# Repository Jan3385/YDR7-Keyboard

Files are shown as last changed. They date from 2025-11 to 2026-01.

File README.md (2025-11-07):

# YDR7-Keyboard

A mechanical keyboard build on YD-RP2040 with an OLED display and backlights

Build for **MX** switches

A sligthly modified 96% keyboard layout with 4 extra keys for managing onboard firmware (103 keys total)

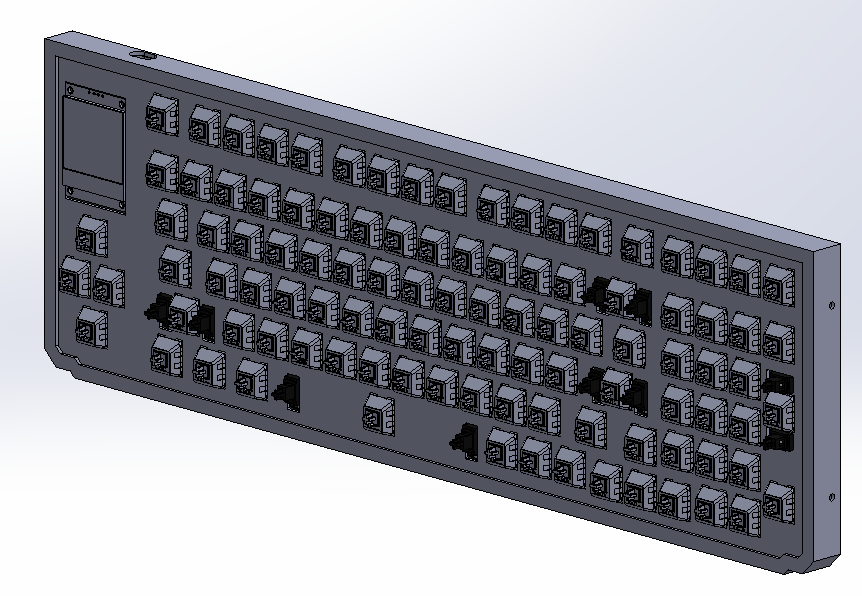
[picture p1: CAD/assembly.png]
Keyboard CAD assembly


Keyboard layout

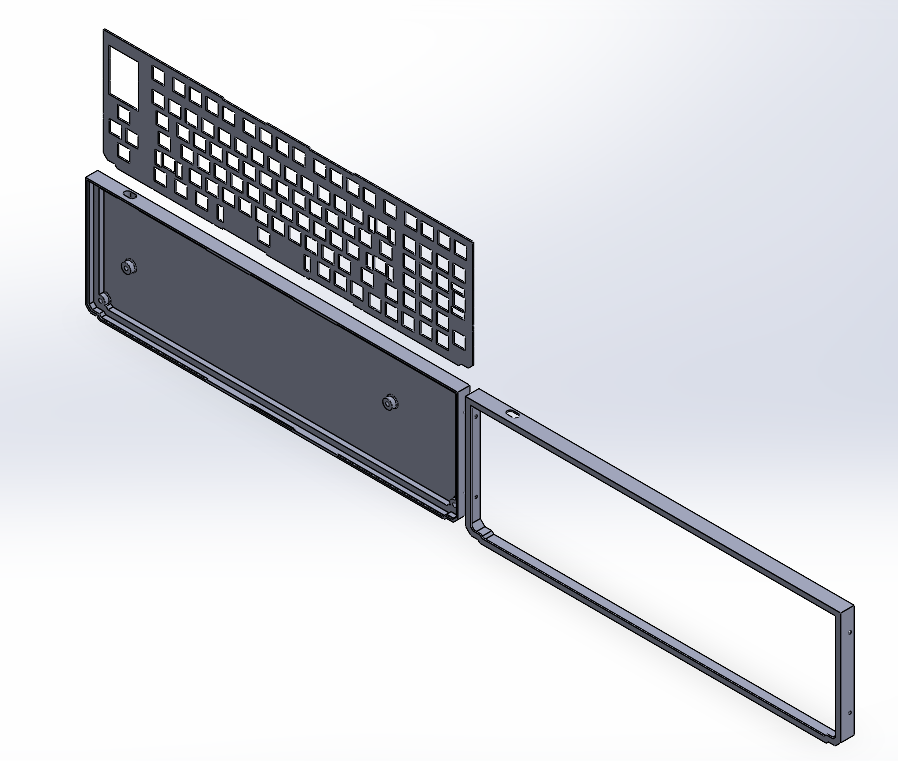
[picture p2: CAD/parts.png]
Keyboard parts


## Why is this one special

It's a keyboard with a customisable OLED that helps to manage, and control parts of the firmware like changing backlighting color, showing typing speed and much more

The firmware is also open-source so anyone can customise and add features to their keyboard

## PCB

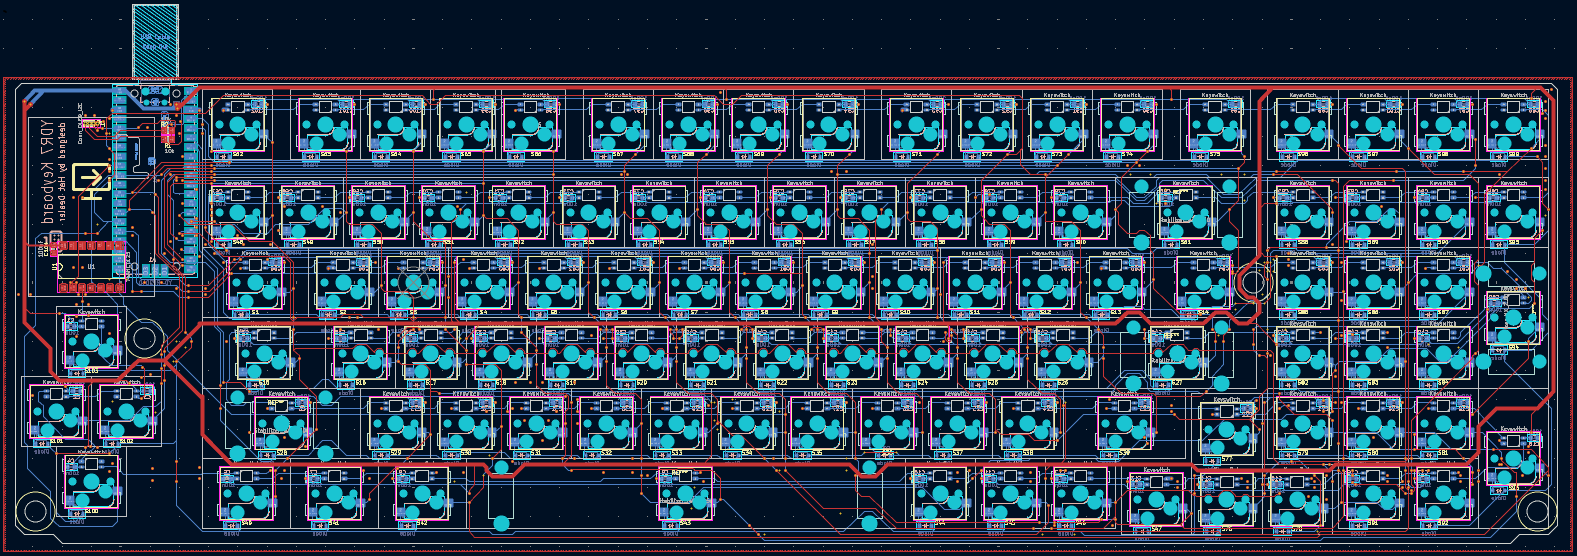
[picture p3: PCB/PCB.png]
PCB


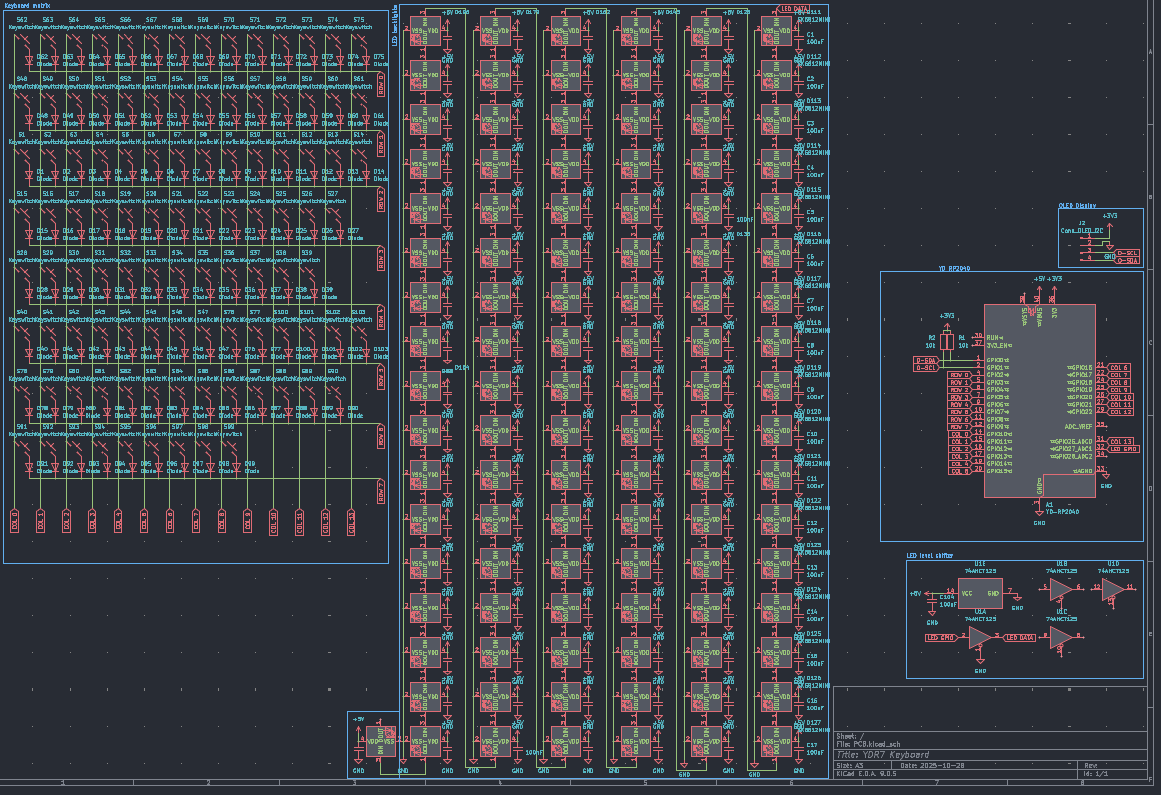
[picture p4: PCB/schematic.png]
Schematic


The keyboard uses a custom PCB with the YD-RP2040 attached to it providing a USB-C connection along with power to the board

The YD-RP2040 is the devboard with a chip running this project. You may be able to use a standard Raspberry PI pico but that was not tested

## Case

The keyboard is comprised out of 3 parts. The panel which holds the switches, a back panel and a front panel

Due to their size its impossible to print an entire piece at once, thats why there are sliced versions in the `CAD/Sliced` folder. You can print them separately and then weld them with a soldering iron together. You should weld the front and the back piece but not the panels as they are held together by the frame anyway

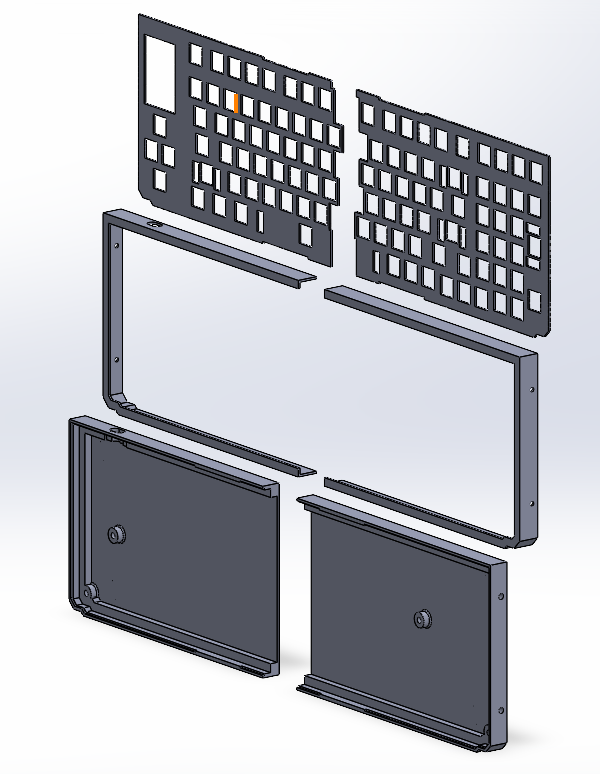
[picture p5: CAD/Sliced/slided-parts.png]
Sliced case


> [!WARNING]
> Due to the size of the keyboard, even the sliced version requires 216 x 139 mm or larger printing plate

## Compiling & flashing firmware

> [!NOTE]
> You should have CMAKE and GCC installed along with Arm embedded GNU Toolchain `arm-none-eabi-gcc`

For compilation run the following commands in the project folder:
Note that the first command may take a while as it is downloading the SDK from git

> cmake -S Firmware -B Firmware/build -G "Ninja"

> cmake --build Firmware/build --target Keyboard_Firmware

To load the firmware into the RP2040 chip, press the **BOOT** button on the YD-RP2040 devboard and plug it into your computer. It should appear as a drive in which you insert the `Keyboard_Firmware.uf2` file inside the `Firmware/build/` folder. The keyboard should reboot itself and load the active firmware

To reflash the board just repeat the steps above

## BOM

| Product name | Product description | Product link | Product unit cost inc. Tax (€) | Product amount | Product total cost (€) | Running total (€ with tax and shipping) |
|---|---|---|---|---|---|---|
| YD-RP2040 | RPI pico-like microcontroller board | [Link](https://www.aliexpress.com/item/1005006152339711.html) | 2.99 € | 1 | 2.99 € | 2.99 € |
| 74AHCT125DR | Logic level shifter IO | [Link](https://www.aliexpress.com/item/1005010022053816.html) | 3.01 € | 1 | 3.01 € | 6.00 € |
| 100nF 0805 Ceramic Capacitor (>= 6.3V) | Decoupling capacitor | [Link](https://www.aliexpress.com/item/1005007470747384.html) | 0.02 € | 105 | 1.82 € | 7.82 € |
| 10kΩ 0805 Resistor | Pull-up resistor | [Link](https://www.aliexpress.com/item/1005009805187579.html) | 0.02 € | 2 | 0.04 € | 7.85 € |
| 1N4148W Diode | Keyboard matrix diode | [Link](https://www.aliexpress.com/item/4000685043735.html) | 0.02 € | 103 | 1.77 € | 9.63 € |
| Kailh Hot-Swap Sockets for Gateron x103 | PCB sockets for switches | [Link](https://www.aliexpress.com/item/1005009594313632.html) | 8.24 € | 1 | 8.24 € | 17.87 € |
| Gateron Switch G Pro 3.0 | Mechanical keyboard switches | [Link](https://kurokeeb.com/products/gateron-switch-g-pro-3-0) | 0.37 € | 103 | 38.11 € | 55.98 € |
| 1.5 Inch OLED Display 128x128 I2C | OLED Screen | [Link](https://www.aliexpress.com/item/1005009409829497.html) | 4.25 € | 1 | 4.25 € | 60.23 € |
| SK6812 Mini RGB LED x200 | Backlight LEDs | [Link](https://www.aliexpress.com/item/1005007696173500.html) | 3.38 € | 2 | 6.76 € | 66.99 € |
| Keycap set | set of keycaps for keyboard | [Link](https://www.aliexpress.com/item/1005007996240625.html) | 16.93 € | 1 | 16.93 € | 83.92 € |
| M3x8 screws | screws for PCB and case assembly | [Link](https://www.aliexpress.com/item/1005008585550992.html) | 0.05 € | 8 | 0.40 € | 84.32 € |
| Hot melt inserts MxL4xOD4.2 | inserts for case assembly | [Link](https://www.aliexpress.com/item/1005006071488810.html) | 0.11 € | 8 | 0.88 € | 85.20 € |
| Silicone feet 12x3mm x4 | anti-slip feet for case | [Link](https://www.aliexpress.com/item/1005006954839245.html) | 0.72 € | 1 | 0.72 € | 85.92 € |
| PCB | w/o assembly (estimate) | [Link](https://www.jlcpcb.com/) | 40.00 € | 1 | 40.00 € | 125.92 € |

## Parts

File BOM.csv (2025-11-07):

Product name | Product description | Product link | Product unit cost inc. Tax (€) | Product amount | Product total cost (€) | Running total (€ with tax and shipping)
YD-RP2040 | RPI pico-like microcontroller board | https://www.aliexpress.com/item/1005006152339711.html | 2.99 € | 1 | 2.99 € | 2.99 €
74AHCT125DR | Logic level shifter IO | https://www.aliexpress.com/item/1005010022053816.html | 3.01 € | 1 | 3.01 € | 6.00 €
100nF 0805 Ceramic Capacitor (>= 6.3V) | Decoupling capacitor | https://www.aliexpress.com/item/1005007470747384.html | 0.02 € | 105 | 1.82 € | 7.82 €
10kΩ 0805 Resistor | Pull-up resistor | https://www.aliexpress.com/item/1005009805187579.html | 0.02 € | 2 | 0.04 € | 7.85 €
1N4148W Diode | Keyboard matrix diode | https://www.aliexpress.com/item/4000685043735.html | 0.02 € | 103 | 1.77 € | 9.63 €
Kailh Hot-Swap Sockets for Gateron x103 | PCB sockets for switches | https://www.aliexpress.com/item/1005009594313632.html | 8.24 € | 1 | 8.24 € | 17.87 €
Gateron Switch G Pro 3.0 | Mechanical keyboard switches | https://kurokeeb.com/products/gateron-switch-g-pro-3-0 | 0.37 € | 103 | 38.11 € | 55.98 €
1.5 Inch OLED Display 128x128 I2C | OLED Screen | https://www.aliexpress.com/item/1005009409829497.html | 4.25 € | 1 | 4.25 € | 60.23 €
SK6812 Mini RGB LED x200 | Backlight LEDs | https://www.aliexpress.com/item/1005007696173500.html | 3.38 € | 2 | 6.76 € | 66.99 €
Keycap set | set of keycaps for keyboard | https://www.aliexpress.com/item/1005007996240625.html | 16.93 € | 1 | 16.93 € | 83.92 €
M3x8 screws | screws for PCB and case assembly | https://www.aliexpress.com/item/1005008585550992.html | 0.05 € | 8 | 0.40 € | 84.32 €
Hot melt inserts MxL4xOD4.2 | inserts for case assembly | https://www.aliexpress.com/item/1005006071488810.html | 0.11 € | 8 | 0.88 € | 85.20 €
Silicone feet 12x3mm x4 | anti-slip feet for case | https://www.aliexpress.com/item/1005006954839245.html | 0.72 € | 1 | 0.72 € | 85.92 €
PCB | w/o assembly (estimate) | https://www.jlcpcb.com/ | 40.00 € | 1 | 40.00 € | 125.92 €

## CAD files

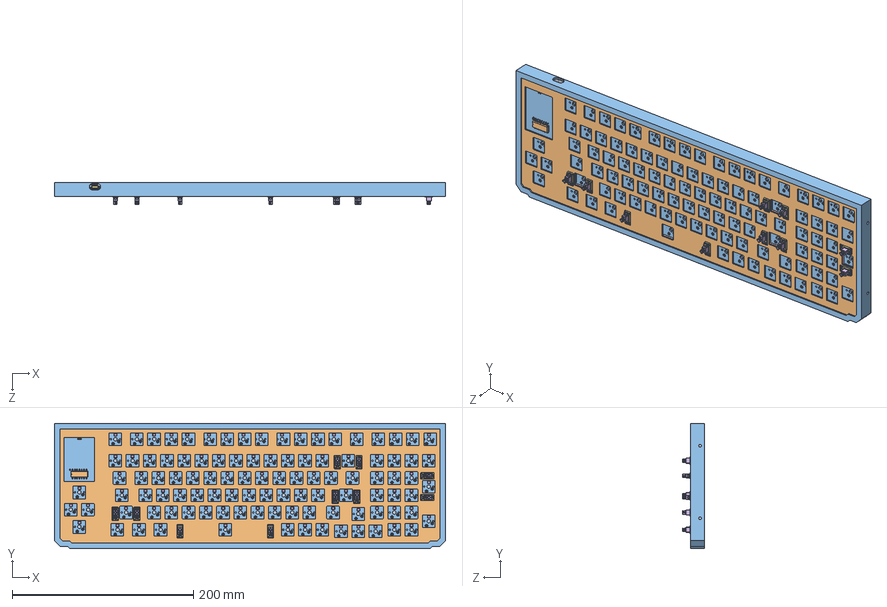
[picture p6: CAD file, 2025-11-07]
CAD/Assembly.STEP
431.7 x 138.0 x 24.4 mm
back
plate
front
Pins.step x 103
Body.step x 103
RaspberryPi_Pico_Module_KiCad.step
Hotswap_MX.step x 103
SMDIP-14_W11.48mm.step
C_0805_2012Metric.step x 105
R_0805_2012Metric.step x 2
Stabilizer_MX_2.00u.step x 4
PinHeader_1x04_P1.00mm_Vertical.step
Stabilizer_MX_6.25u.step
Diode_SOD-123.step x 103
PCB_PCB.step

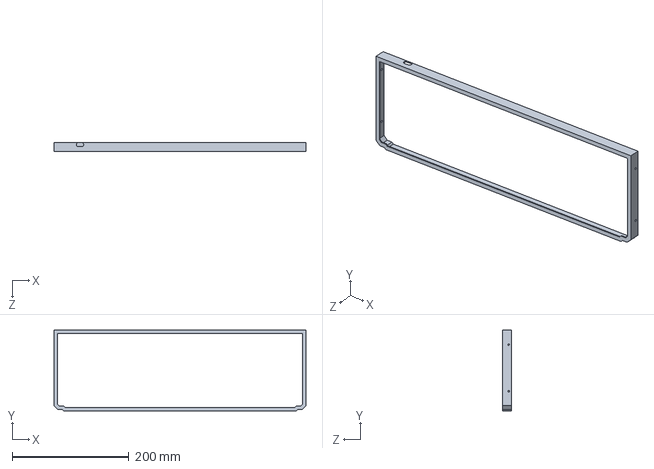
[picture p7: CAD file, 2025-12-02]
CAD/front.SLDPRT
431.7 x 138.0 x 15.6 mm

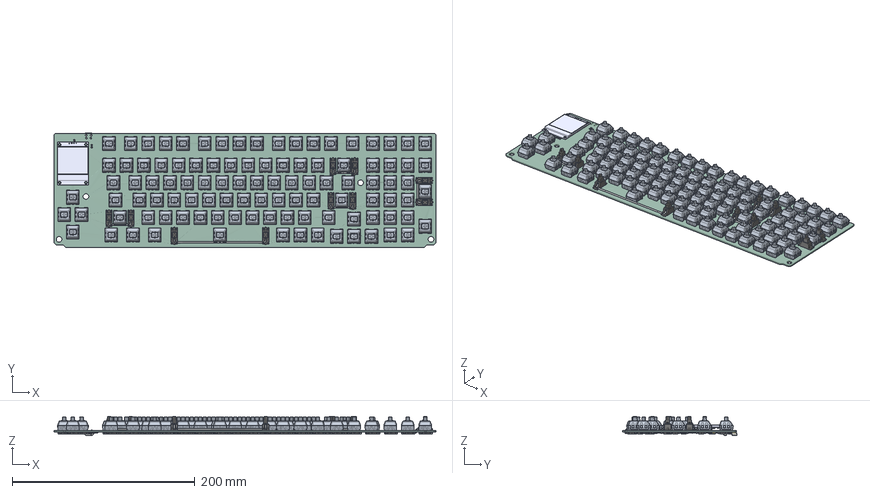
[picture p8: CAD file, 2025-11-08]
PCB/PCB.step
418.3 x 125.4 x 20.8 mm
Hotswap_MX x 103
PCB 1.2.1 x 103
SMDIP-14_W11.48mm
C_0805_2012Metric x 105
R_0805_2012Metric x 2
Stabilizer_MX_2.00u x 4
PinHeader_1x04_P1.00mm_Vertical
Part1_without header pins
Stabilizer_MX_6.25u
Pins x 103
Diode_SOD-123 x 103
RaspberryPi_Pico_Module_KiCad
PCB_PCB

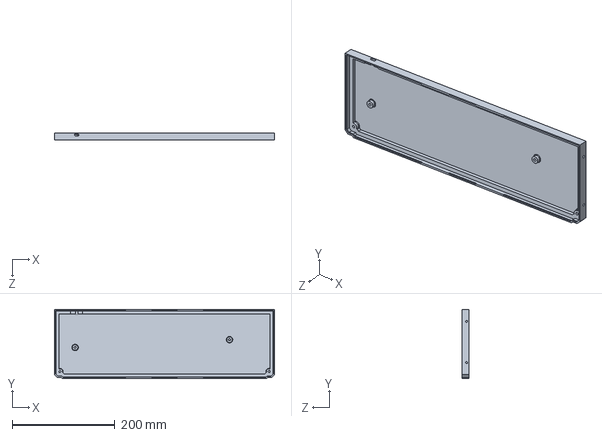
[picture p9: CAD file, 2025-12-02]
CAD/Back.SLDPRT
428.3 x 134.6 x 14.0 mm

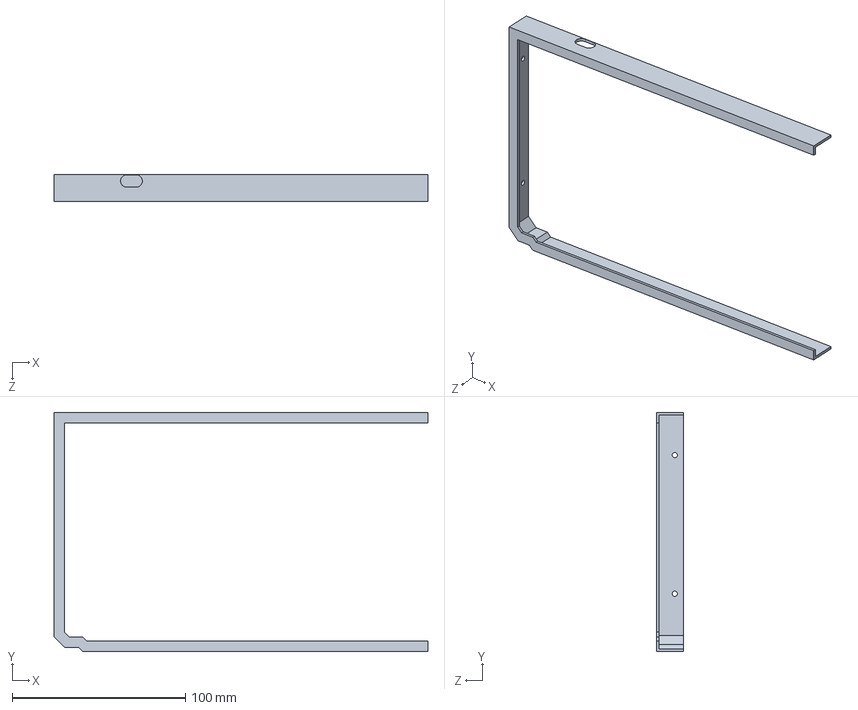
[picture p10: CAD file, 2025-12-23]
CAD/Sliced/1-front.STEP
215.8 x 138.0 x 15.6 mm

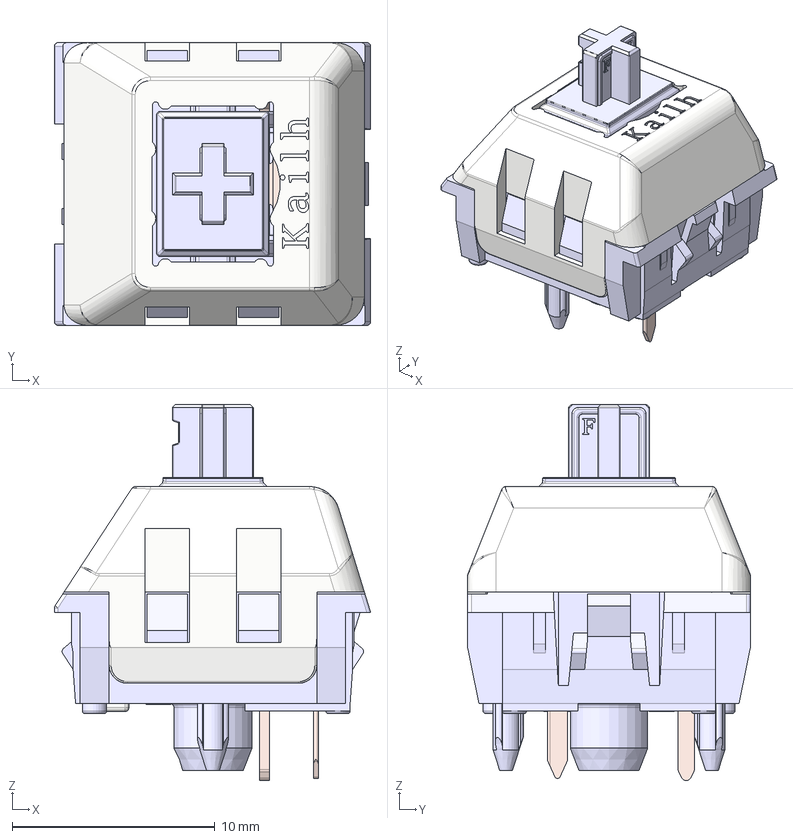
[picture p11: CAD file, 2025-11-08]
PCB/Kailh Polia.step
15.6 x 14.0 x 18.5 mm
Housing
ThickContact
SpringContact
Stem
Lid

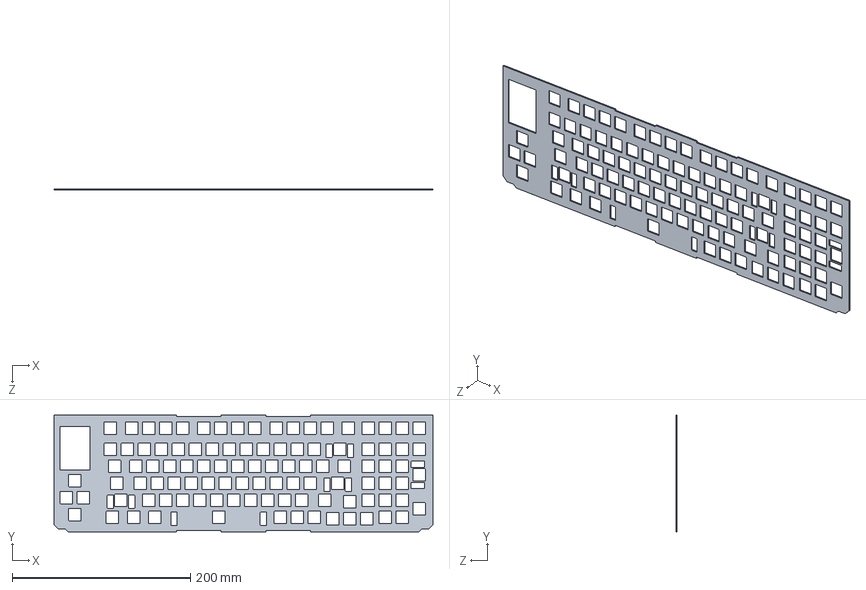
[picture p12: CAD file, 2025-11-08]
CAD/plate.STEP
424.8 x 130.6 x 1.50 mm

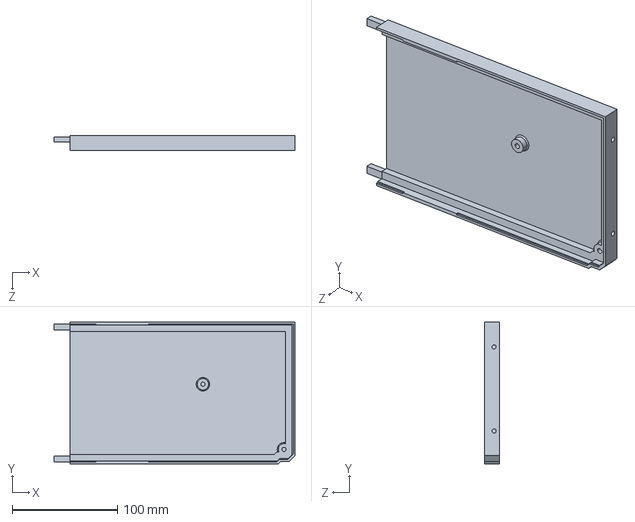
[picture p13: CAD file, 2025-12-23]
CAD/Sliced/2-back.STEP
229.1 x 134.6 x 14.1 mm

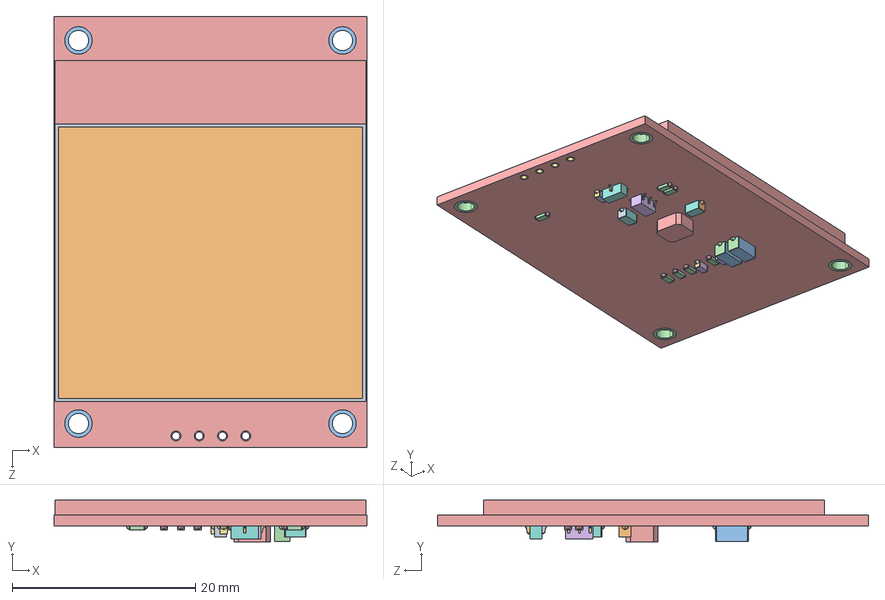
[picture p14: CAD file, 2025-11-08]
PCB/SH1107 oled (without header pins).STEP
34.1 x 4.56 x 47.1 mm
Part1_without header pins

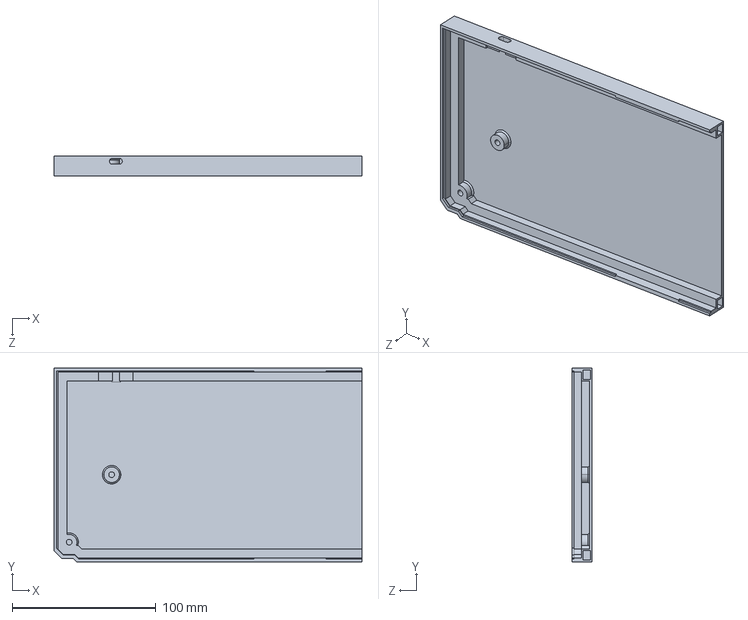
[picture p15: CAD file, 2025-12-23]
CAD/Sliced/1-back.STEP
214.1 x 134.6 x 14.1 mm

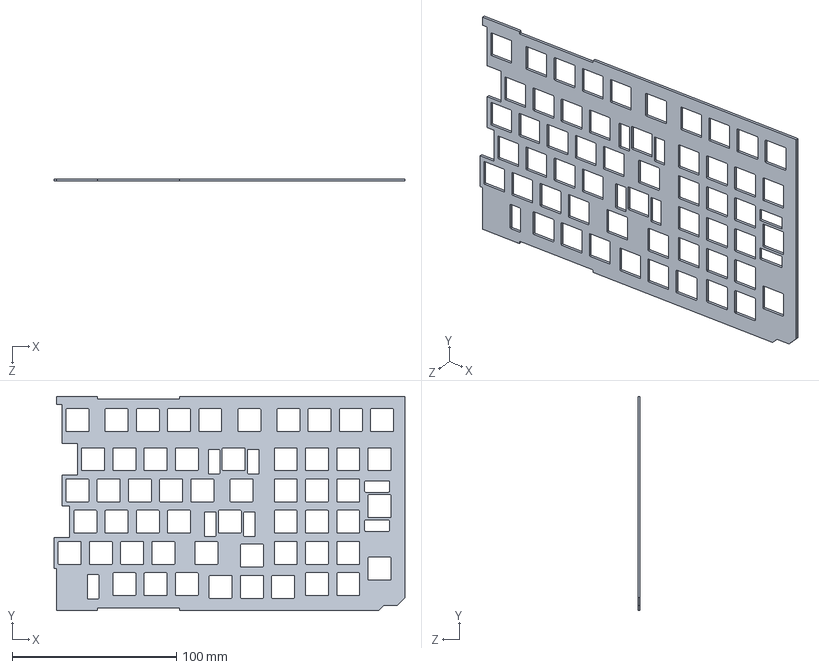
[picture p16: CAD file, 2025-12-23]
CAD/Sliced/2-plate.STEP
214.0 x 130.6 x 1.50 mm

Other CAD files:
CAD/Sliced/Assembly.STEP
CAD/Sliced/1-plate.STEP
CAD/Sliced/2-front.STEP
CAD/Assembly.SLDASM
CAD/Sliced/1-back.SLDPRT
CAD/Sliced/1-back.STL
CAD/Sliced/1-front.SLDPRT
CAD/Sliced/1-front.STL
CAD/Sliced/1-plate.3mf
CAD/Sliced/1-plate.SLDPRT
CAD/Sliced/1-plate.STL
CAD/Sliced/2-back.SLDPRT
CAD/Sliced/2-back.STL
CAD/Sliced/2-front.SLDPRT
CAD/Sliced/2-front.STL
CAD/Sliced/2-plate.SLDPRT
CAD/Sliced/2-plate.STL
CAD/Sliced/Assembly.SLDASM
CAD/back.STL
CAD/plate.SLDPRT
CAD/plate.STL

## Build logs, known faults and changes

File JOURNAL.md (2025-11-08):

<!--
  ===================    !!READ THIS NOTICE!!   ====================
  DO NOT edit this file manually. Your changes WILL BE OVERWRITTEN!
  This journal is auto generated and updated by Hack Club Blueprint.
  To edit this file, please edit your journal entries on Blueprint.
  ==================================================================
-->

## 10/28/2025 - Setup & research  

I have done some research about which devboard, switches etc to use. I also setup the github with KiCad and such. Mentally planned out where I want what, which features should the keyboard have and which not



## 10/29/2025 1 PM - Designed the schematic and searched for parts  

I made the (maybe) final schematic for my keyboard. The number of switches and LEDs will probably go down as I am not yet totally sure how much will I need but thats about it. I have put a 128x128 OLED display on the keyboard along with an RGB LED below each key of the keyboard so it should be looking (and working) pretty good once finished



I also tried to find all the parts that I will yet need from aliexpress and similar. I have not found all of them but most

Also I looked somewhat onto how to code the firmware later on and such which I am planning to do in C++ and have a custom interactible menu on the OLED along with some animations etc

## 10/29/2025 6 PM - Started making the PCB  

Started making the PCB, mainly the keys and their diodes. I will have to remake the schematic for the keys since it doesnt fit well with how I ended up placing them on the PCB

ALso improved on the schematic like adding pull-up resistors for the I2C for display communication and such



## 11/1/2025 1 AM - Finished the wiring of the PCB  

I wired up all the LEDs and buttons on the PCB along with resistors etc. At first I had a lot of errors to go through but most of them were fixed by just changing the tolerances and stitching the PCB



After stitching the PCB, changing tolerances etc I had 0 errors (whe warnings are mostly fine as its just isolated copper fills)







I am not totally done with the PCB as I will have to check if everything actually works etc but it should be done for the most part  

## 11/1/2025 9 PM - Basic Firmware  

I have written a basic firmware for the keyboard where I mapped all the pins and made it write the letter "A" on loop as a keyboard. I have written it in C++ since its more fun and probably gives more control than for ex. Python. I was focusing on making the firmware basics easy to modify and configure



## 11/5/2025 5 PM - CAD model for keyboard assembly  

I made the keyboard assembly in CAD. The front plate is for holding switches and the back for screwing in the PCB and such. I will probably edit it a little in the future like adding space for rubber feet etc but I wont probably even make a journal for it



I also made a few improvements to the PCB and double-checked everything I thought of

I will do few smaller things like finishing the README, BOM etc and then the project should be ready for manufacturing  

## 11/5/2025 8 PM - Finishing up + sliced CAD versions  

I finished up most of the project like BOM, README and such

Also due to the size of a keyboard which is really big I made sliced versions of the case which can be printed separately and welded together with a soldering iron after



## 11/6/2025 - README, BOM & PCB updates, finalizing  

Updated the README, BOM and the PCB with a capacitor, grounding some pins etc



Generally finalized the project, double-checked some stuff etc. just so I can be pretty sure most of it is right  

## 11/7/2025 - BOM updated and made final CAD assembly  

I updated my BOM to lower the price as much as I think I safely can without ordering parts that wont work or for example switches that dont support RGB etc. Also got banned on aliexpress for making my first account for some reason lol

I will also keep the SMDs since I already have most of the SMD parts at home so I wont be using the grant to buy them and I know how to solder them reliably

The final cost will be lower since I wont be buying most SMD components, screws, hot-melt inserts etc. but I am making the BOM for a person that only has basic components like a soldering iron and solder wire so thats why I put them there

Also made the final assembly with the PCB inside of it

assembly

## 11/8/2025 - Fixed PCB and updated assembly  

I fixed an issue with the PCB having one switch incorrectly offseted so I had to fix that row which took a while and after that I searched for 3D files for the OLED and switches to add to the assembly. I didnt find the exact match for the display as it has a bit wierd pinout but I think it server well enough for the purpose of showing how the final product will look like

I first tried to put the switches into the assembly directly but after some time I realized it was easier to just modify the 3D part for the switches on the PCB directly



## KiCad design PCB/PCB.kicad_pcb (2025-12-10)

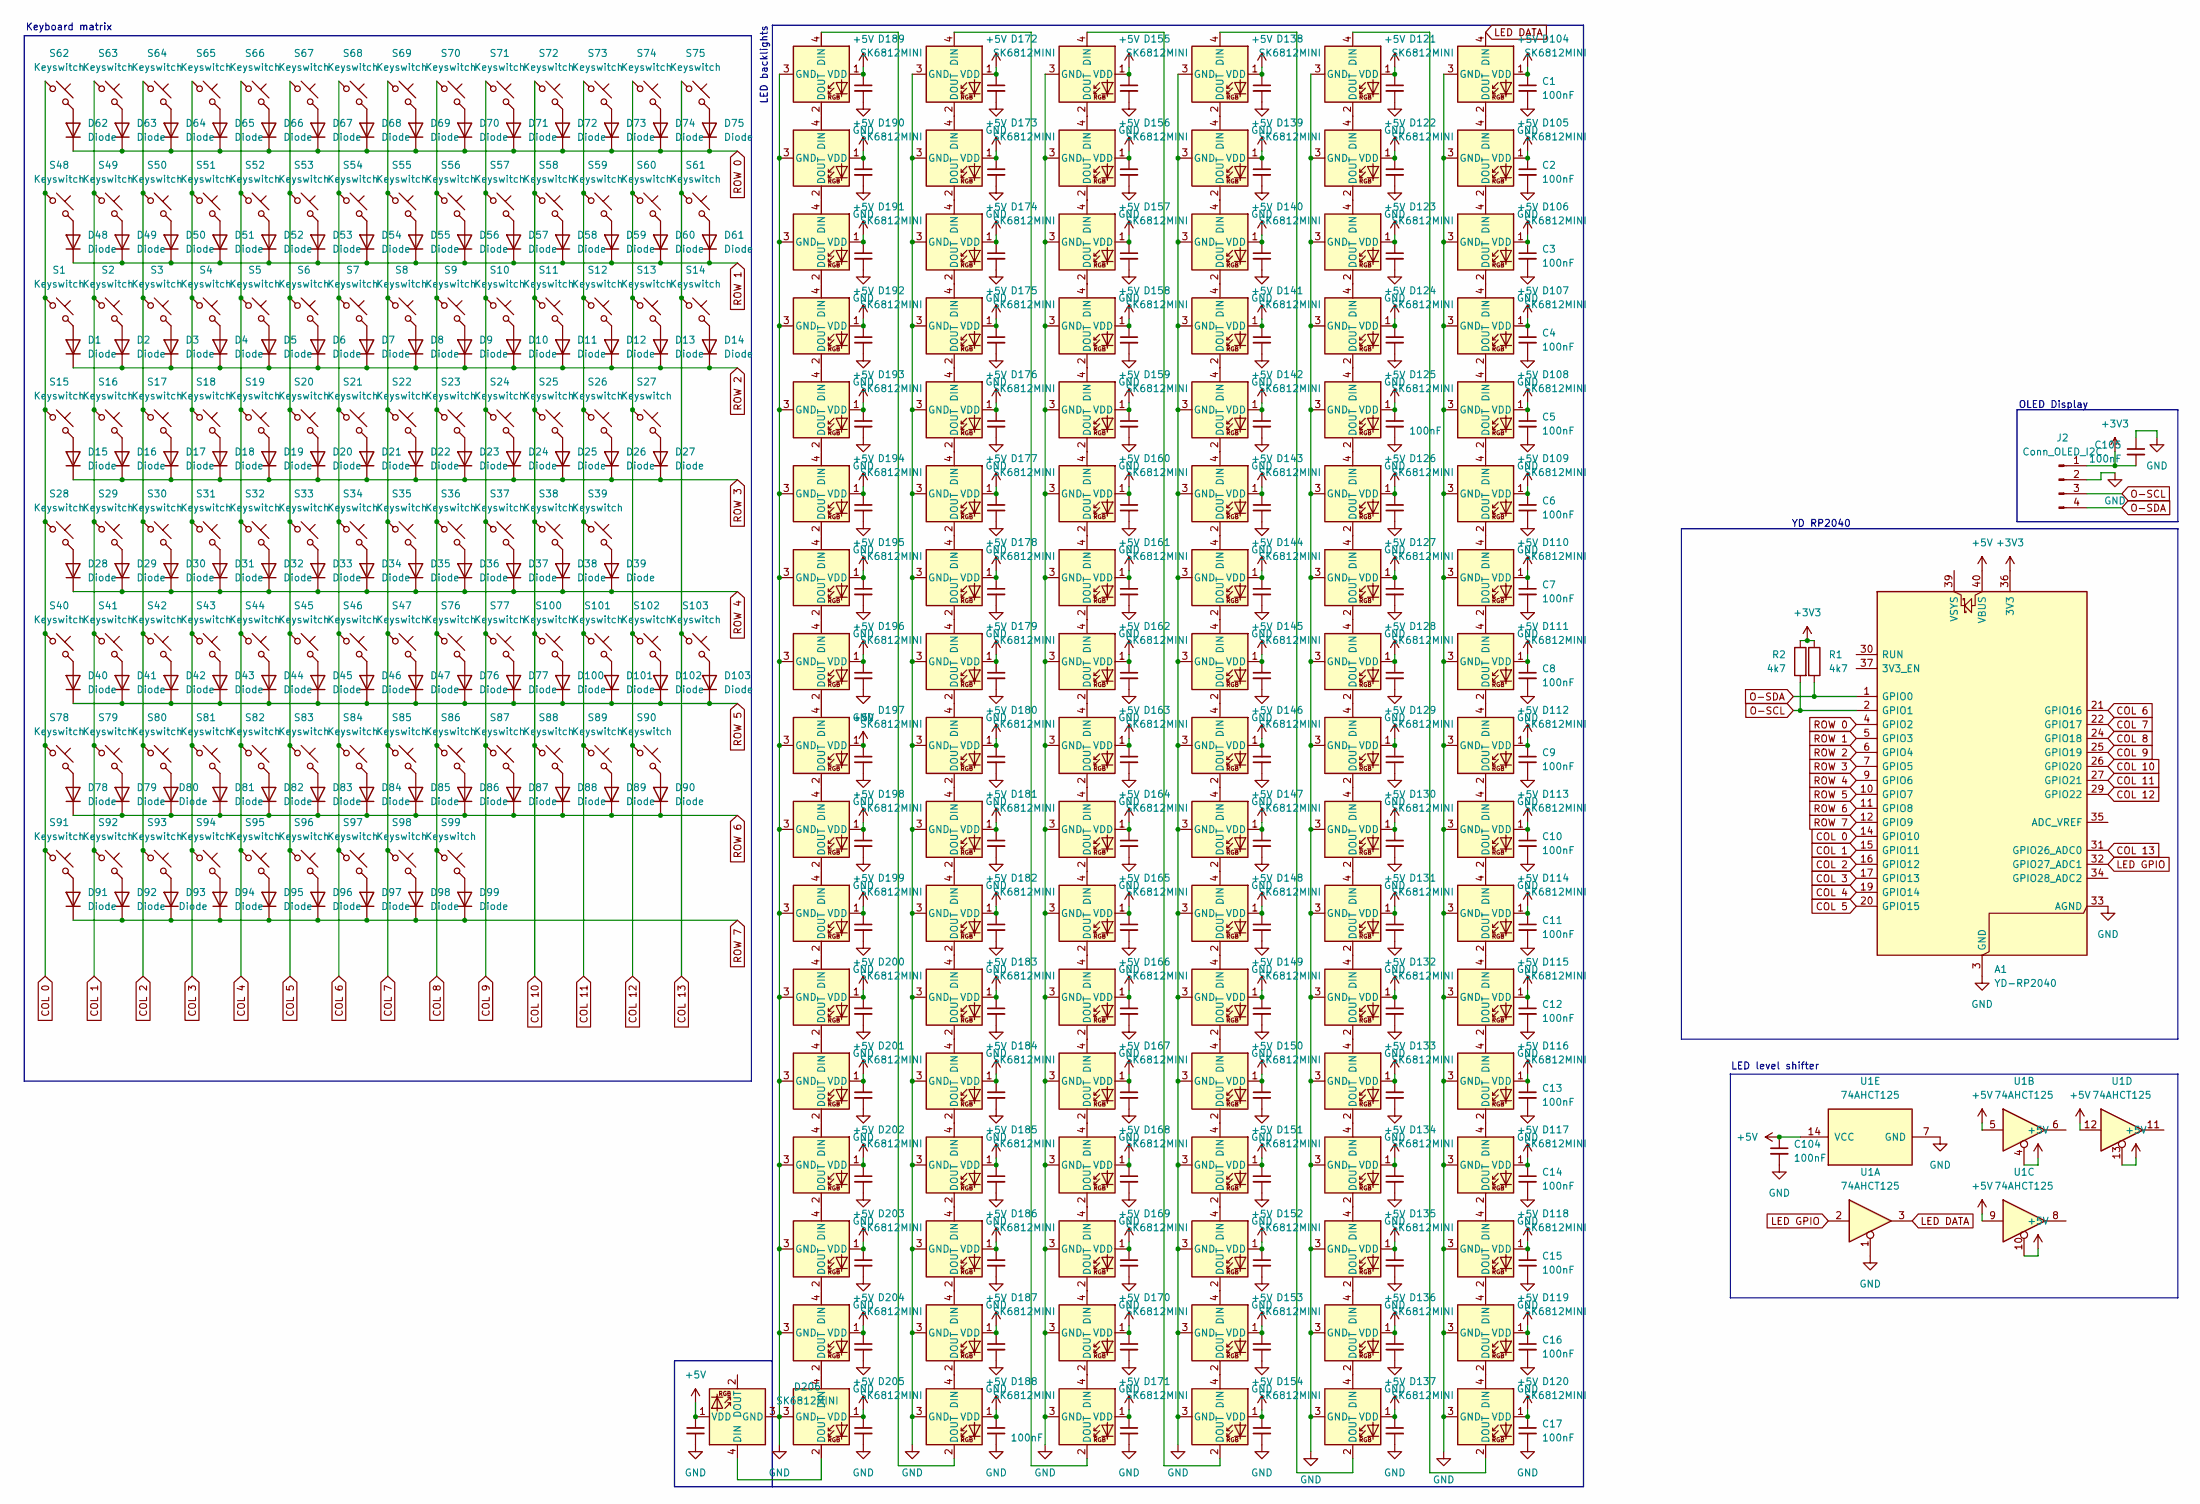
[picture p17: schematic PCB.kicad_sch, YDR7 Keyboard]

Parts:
A1: YD-RP2040; RaspberryPi_Pico_SMD_HandSolder
C1, C2, C3, C4, C5, C6, C7, C8, C9, C10, C11, C12, C13, C14, C15, C16, C17, C18, C19, C20, C21, C22, C23, C24, C25, C26, C27, C28, C29, C30, C31, C32, C33, C34, C35, C36, C37, C38, C39, C40, C41, C42, C43, C44, C45, C46, C47, C48, C49, C50, C51, C52, C53, C54, C55, C56, C57, C58, C59, C60, C61, C62, C63, C64, C65, C66, C67, C68, C69, C70, C71, C72, C73, C74, C75, C76, C77, C78, C79, C80, C81, C82, C83, C84, C85, C86, C87, C88, C89, C90, C91, C92, C93, C94, C95, C96, C97, C98, C99, C100, C101, C102, C103, C104, C105: 100nF; C_0805_2012Metric_Pad1.18x1.45mm_HandSolder
D1, D2, D3, D4, D5, D6, D7, D8, D9, D10, D11, D12, D13, D14, D15, D16, D17, D18, D19, D20, D21, D22, D23, D24, D25, D26, D27, D28, D29, D30, D31, D32, D33, D34, D35, D36, D37, D38, D39, D40, D41, D42, D43, D44, D45, D46, D47, D48, D49, D50, D51, D52, D53, D54, D55, D56, D57, D58, D59, D60, D61, D62, D63, D64, D65, D66, D67, D68, D69, D70, D71, D72, D73, D74, D75, D76, D77, D78, D79, D80, D81, D82, D83, D84, D85, D86, D87, D88, D89, D90, D91, D92, D93, D94, D95, D96, D97, D98, D99, D100, D101, D102, D103: Diode; Diode_SOD-123
D104, D105, D106, D107, D108, D109, D110, D111, D112, D113, D114, D115, D116, D117, D118, D119, D120, D121, D122, D123, D124, D125, D126, D127, D128, D129, D130, D131, D132, D133, D134, D135, D136, D137, D138, D139, D140, D141, D142, D143, D144, D145, D146, D147, D148, D149, D150, D151, D152, D153, D154, D155, D156, D157, D158, D159, D160, D161, D162, D163, D164, D165, D166, D167, D168, D169, D170, D171, D172, D173, D174, D175, D176, D177, D178, D179, D180, D181, D182, D183, D184, D185, D186, D187, D188, D189, D190, D191, D192, D193, D194, D195, D196, D197, D198, D199, D200, D201, D202, D203, D204, D205, D206: SK6812MINI; LED_SK6812MINI
J2: Conn_OLED_I2C; PinHeader_1x04_P2.54mm_Vertical
R1, R2: 4k7; R_0805_2012Metric_Pad1.20x1.40mm_HandSolder
S1, S14: Keyswitch; Hotswap_MX_1.50u
S2, S3, S4, S5, S6, S7, S8, S9, S10, S11, S12, S13, S16, S17, S18, S19, S20, S21, S22, S23, S24, S25, S26, S29, S30, S31, S32, S33, S34, S35, S36, S37, S38, S44, S45, S46, S47, S48, S49, S50, S51, S52, S53, S54, S55, S56, S57, S58, S59, S60, S62, S63, S64, S65, S66, S67, S68, S69, S70, S71, S72, S73, S74, S75, S76, S77, S78, S79, S80, S81, S82, S83, S84, S85, S86, S87, S88, S89, S90, S91, S92, S95, S96, S97, S98, S99, S100, S101, S102, S103: Keyswitch; Hotswap_MX_1.00u
S15, S39: Keyswitch; Hotswap_MX_1.75u
S27, S28: Keyswitch; Hotswap_MX_2.25u
S40, S41, S42: Keyswitch; Hotswap_MX_1.25u
S43: Keyswitch; Hotswap_MX_6.25u
S61: Keyswitch; Hotswap_MX_2.00u
S93, S94: Keyswitch; Hotswap_MX_2.00u_90deg
U1: 74AHCT125; SOIC-14_3.9x8.7mm_P1.27mm

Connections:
+3V3: A1.36 (3V3), C105.2, J2.1, R1.1, R2.1
+5V: A1.40 (VBUS), C1.1, C2.1, C3.1, C4.1, C5.1, C6.1, C7.1, C8.1, C9.1, C10.1, C11.1, C12.1, C13.1, C14.1, C15.1, C16.1, C17.1, C18.1, C19.1, C20.1, C21.1, C22.1, C23.1, C24.1, C25.1, C26.1, C27.1, C28.1, C29.1, C30.1, C31.1, C32.1, C33.1, C34.1, C35.1, C36.1, C37.1, C38.1, C39.1, C40.1, C41.1, C42.1, C43.1, C44.1, C45.1, C46.1, C47.1, C48.1, C49.1, C50.1, C51.1, C52.1, C53.1, C54.1, C55.1, C56.1, C57.1, C58.1, C59.1, C60.1, C61.1, C62.1, C63.1, C64.1, C65.1, C66.1, C67.1, C68.1, C69.1, C70.1, C71.1, C72.1, C73.1, C74.1, C75.1, C76.1, C77.1, C78.1, C79.1, C80.1, C81.1, C82.1, C83.1, C84.1, C85.1, C86.1, C87.1, C88.1, C89.1, C90.1, C91.1, C92.1, C93.1, C94.1, C95.1, C96.1, C97.1, C98.1, C99.1, C100.1, C101.1, C102.1, C103.1, C104.1, D104.1 (VDD), D105.1 (VDD), D106.1 (VDD), D107.1 (VDD), D108.1 (VDD), D109.1 (VDD), D110.1 (VDD), D111.1 (VDD), D112.1 (VDD), D113.1 (VDD), D114.1 (VDD), D115.1 (VDD), D116.1 (VDD), D117.1 (VDD), D118.1 (VDD), D119.1 (VDD), D120.1 (VDD), D121.1 (VDD), D122.1 (VDD), D123.1 (VDD), D124.1 (VDD), D125.1 (VDD), D126.1 (VDD), D127.1 (VDD), D128.1 (VDD), D129.1 (VDD), D130.1 (VDD), D131.1 (VDD), D132.1 (VDD), D133.1 (VDD), D134.1 (VDD), D135.1 (VDD), D136.1 (VDD), D137.1 (VDD), D138.1 (VDD), D139.1 (VDD), D140.1 (VDD), D141.1 (VDD), D142.1 (VDD), D143.1 (VDD), D144.1 (VDD), D145.1 (VDD), D146.1 (VDD), D147.1 (VDD), D148.1 (VDD), D149.1 (VDD), D150.1 (VDD), D151.1 (VDD), D152.1 (VDD), D153.1 (VDD), D154.1 (VDD), D155.1 (VDD), D156.1 (VDD), D157.1 (VDD), D158.1 (VDD), D159.1 (VDD), D160.1 (VDD), D161.1 (VDD), D162.1 (VDD), D163.1 (VDD), D164.1 (VDD), D165.1 (VDD), D166.1 (VDD), D167.1 (VDD), D168.1 (VDD), D169.1 (VDD), D170.1 (VDD), D171.1 (VDD), D172.1 (VDD), D173.1 (VDD), D174.1 (VDD), D175.1 (VDD), D176.1 (VDD), D177.1 (VDD), D178.1 (VDD), D179.1 (VDD), D180.1 (VDD), D181.1 (VDD), D182.1 (VDD), D183.1 (VDD), D184.1 (VDD), D185.1 (VDD), D186.1 (VDD), D187.1 (VDD), D188.1 (VDD), D189.1 (VDD), D190.1 (VDD), D191.1 (VDD), D192.1 (VDD), D193.1 (VDD), D194.1 (VDD), D195.1 (VDD), D196.1 (VDD), D197.1 (VDD), D198.1 (VDD), D199.1 (VDD), D200.1 (VDD), D201.1 (VDD), D202.1 (VDD), D203.1 (VDD), D204.1 (VDD), D205.1 (VDD), D206.1 (VDD), U1.4, U1.5, U1.9, U1.10, U1.12, U1.13, U1.14 (VCC)
COL 0: A1.14 (GPIO10), S1.1, S15.1, S28.1, S40.1, S48.1, S62.1, S78.1, S91.1
COL 1: A1.15 (GPIO11), S2.1, S16.1, S29.1, S41.1, S49.1, S63.1, S79.1, S92.1
COL 2: A1.16 (GPIO12), S3.1, S17.1, S30.1, S42.1, S50.1, S64.1, S80.1, S93.1
COL 3: A1.17 (GPIO13), S4.1, S18.1, S31.1, S43.1, S51.1, S65.1, S81.1, S94.1
COL 4: A1.19 (GPIO14), S5.1, S19.1, S32.1, S44.1, S52.1, S66.1, S82.1, S95.1
COL 5: A1.20 (GPIO15), S6.1, S20.1, S33.1, S45.1, S53.1, S67.1, S83.1, S96.1
COL 6: A1.21 (GPIO16), S7.1, S21.1, S34.1, S46.1, S54.1, S68.1, S84.1, S97.1
COL 7: A1.22 (GPIO17), S8.1, S22.1, S35.1, S47.1, S55.1, S69.1, S85.1, S98.1
COL 8: A1.24 (GPIO18), S9.1, S23.1, S36.1, S56.1, S70.1, S76.1, S86.1, S99.1
COL 9: A1.25 (GPIO19), S10.1, S24.1, S37.1, S57.1, S71.1, S77.1, S87.1
COL 10: A1.26 (GPIO20), S11.1, S25.1, S38.1, S58.1, S72.1, S88.1, S100.1
COL 11: A1.27 (GPIO21), S12.1, S26.1, S39.1, S59.1, S73.1, S89.1, S101.1
COL 12: A1.29 (GPIO22), S13.1, S27.1, S60.1, S74.1, S90.1, S102.1
COL 13: A1.31 (GPIO26_ADC0), S14.1, S61.1, S75.1, S103.1
GND: A1.3 (GND), A1.8 (GND), A1.13 (GND), A1.18 (GND), A1.23 (GND), A1.28 (GND), A1.33 (AGND), A1.38 (GND), C1.2, C2.2, C3.2, C4.2, C5.2, C6.2, C7.2, C8.2, C9.2, C10.2, C11.2, C12.2, C13.2, C14.2, C15.2, C16.2, C17.2, C18.2, C19.2, C20.2, C21.2, C22.2, C23.2, C24.2, C25.2, C26.2, C27.2, C28.2, C29.2, C30.2, C31.2, C32.2, C33.2, C34.2, C35.2, C36.2, C37.2, C38.2, C39.2, C40.2, C41.2, C42.2, C43.2, C44.2, C45.2, C46.2, C47.2, C48.2, C49.2, C50.2, C51.2, C52.2, C53.2, C54.2, C55.2, C56.2, C57.2, C58.2, C59.2, C60.2, C61.2, C62.2, C63.2, C64.2, C65.2, C66.2, C67.2, C68.2, C69.2, C70.2, C71.2, C72.2, C73.2, C74.2, C75.2, C76.2, C77.2, C78.2, C79.2, C80.2, C81.2, C82.2, C83.2, C84.2, C85.2, C86.2, C87.2, C88.2, C89.2, C90.2, C91.2, C92.2, C93.2, C94.2, C95.2, C96.2, C97.2, C98.2, C99.2, C100.2, C101.2, C102.2, C103.2, C104.2, C105.1, D104.3 (GND), D105.3 (GND), D106.3 (GND), D107.3 (GND), D108.3 (GND), D109.3 (GND), D110.3 (GND), D111.3 (GND), D112.3 (GND), D113.3 (GND), D114.3 (GND), D115.3 (GND), D116.3 (GND), D117.3 (GND), D118.3 (GND), D119.3 (GND), D120.3 (GND), D121.3 (GND), D122.3 (GND), D123.3 (GND), D124.3 (GND), D125.3 (GND), D126.3 (GND), D127.3 (GND), D128.3 (GND), D129.3 (GND), D130.3 (GND), D131.3 (GND), D132.3 (GND), D133.3 (GND), D134.3 (GND), D135.3 (GND), D136.3 (GND), D137.3 (GND), D138.3 (GND), D139.3 (GND), D140.3 (GND), D141.3 (GND), D142.3 (GND), D143.3 (GND), D144.3 (GND), D145.3 (GND), D146.3 (GND), D147.3 (GND), D148.3 (GND), D149.3 (GND), D150.3 (GND), D151.3 (GND), D152.3 (GND), D153.3 (GND), D154.3 (GND), D155.3 (GND), D156.3 (GND), D157.3 (GND), D158.3 (GND), D159.3 (GND), D160.3 (GND), D161.3 (GND), D162.3 (GND), D163.3 (GND), D164.3 (GND), D165.3 (GND), D166.3 (GND), D167.3 (GND), D168.3 (GND), D169.3 (GND), D170.3 (GND), D171.3 (GND), D172.3 (GND), D173.3 (GND), D174.3 (GND), D175.3 (GND), D176.3 (GND), D177.3 (GND), D178.3 (GND), D179.3 (GND), D180.3 (GND), D181.3 (GND), D182.3 (GND), D183.3 (GND), D184.3 (GND), D185.3 (GND), D186.3 (GND), D187.3 (GND), D188.3 (GND), D189.3 (GND), D190.3 (GND), D191.3 (GND), D192.3 (GND), D193.3 (GND), D194.3 (GND), D195.3 (GND), D196.3 (GND), D197.3 (GND), D198.3 (GND), D199.3 (GND), D200.3 (GND), D201.3 (GND), D202.3 (GND), D203.3 (GND), D204.3 (GND), D205.3 (GND), D206.3 (GND), J2.2, U1.1, U1.7 (GND)
LED DATA: D104.4 (DIN), U1.3
LED GPIO: A1.32 (GPIO27_ADC1), U1.2
unnamed: D1.2 (A), S1.2
unnamed: D2.2 (A), S2.2
unnamed: D3.2 (A), S3.2
unnamed: D4.2 (A), S4.2
unnamed: D5.2 (A), S5.2
unnamed: D6.2 (A), S6.2
unnamed: D7.2 (A), S7.2
unnamed: D8.2 (A), S8.2
unnamed: D9.2 (A), S9.2
unnamed: D10.2 (A), S10.2
unnamed: D11.2 (A), S11.2
unnamed: D12.2 (A), S12.2
unnamed: D13.2 (A), S13.2
unnamed: D14.2 (A), S14.2
unnamed: D15.2 (A), S15.2
unnamed: D16.2 (A), S16.2
unnamed: D17.2 (A), S17.2
unnamed: D18.2 (A), S18.2
unnamed: D19.2 (A), S19.2
unnamed: D20.2 (A), S20.2
unnamed: D21.2 (A), S21.2
unnamed: D22.2 (A), S22.2
unnamed: D23.2 (A), S23.2
unnamed: D24.2 (A), S24.2
unnamed: D25.2 (A), S25.2
unnamed: D26.2 (A), S26.2
unnamed: D27.2 (A), S27.2
unnamed: D28.2 (A), S28.2
unnamed: D29.2 (A), S29.2
unnamed: D30.2 (A), S30.2
unnamed: D31.2 (A), S31.2
unnamed: D32.2 (A), S32.2
unnamed: D33.2 (A), S33.2
unnamed: D34.2 (A), S34.2
unnamed: D35.2 (A), S35.2
unnamed: D36.2 (A), S36.2
unnamed: D37.2 (A), S37.2
unnamed: D38.2 (A), S38.2
unnamed: D39.2 (A), S39.2
unnamed: D40.2 (A), S40.2
unnamed: D41.2 (A), S41.2
unnamed: D42.2 (A), S42.2
unnamed: D43.2 (A), S43.2
unnamed: D44.2 (A), S44.2
unnamed: D45.2 (A), S45.2
unnamed: D46.2 (A), S46.2
unnamed: D47.2 (A), S47.2
unnamed: D48.2 (A), S48.2
unnamed: D49.2 (A), S49.2
unnamed: D50.2 (A), S50.2
unnamed: D51.2 (A), S51.2
unnamed: D52.2 (A), S52.2
unnamed: D53.2 (A), S53.2
unnamed: D54.2 (A), S54.2
unnamed: D55.2 (A), S55.2
unnamed: D56.2 (A), S56.2
unnamed: D57.2 (A), S57.2
unnamed: D58.2 (A), S58.2
unnamed: D59.2 (A), S59.2
unnamed: D60.2 (A), S60.2
unnamed: D61.2 (A), S61.2
unnamed: D62.2 (A), S62.2
unnamed: D63.2 (A), S63.2
unnamed: D64.2 (A), S64.2
unnamed: D65.2 (A), S65.2
unnamed: D66.2 (A), S66.2
unnamed: D67.2 (A), S67.2
unnamed: D68.2 (A), S68.2
unnamed: D69.2 (A), S69.2
unnamed: D70.2 (A), S70.2
unnamed: D71.2 (A), S71.2
unnamed: D72.2 (A), S72.2
unnamed: D73.2 (A), S73.2
unnamed: D74.2 (A), S74.2
unnamed: D75.2 (A), S75.2
unnamed: D76.2 (A), S76.2
unnamed: D77.2 (A), S77.2
unnamed: D78.2 (A), S78.2
unnamed: D79.2 (A), S79.2
unnamed: D80.2 (A), S80.2
unnamed: D81.2 (A), S81.2
unnamed: D82.2 (A), S82.2
unnamed: D83.2 (A), S83.2
unnamed: D84.2 (A), S84.2
unnamed: D85.2 (A), S85.2
unnamed: D86.2 (A), S86.2
unnamed: D87.2 (A), S87.2
unnamed: D88.2 (A), S88.2
unnamed: D89.2 (A), S89.2
unnamed: D90.2 (A), S90.2
unnamed: D91.2 (A), S91.2
unnamed: D92.2 (A), S92.2
unnamed: D93.2 (A), S93.2
unnamed: D94.2 (A), S94.2
unnamed: D95.2 (A), S95.2
unnamed: D96.2 (A), S96.2
unnamed: D97.2 (A), S97.2
unnamed: D98.2 (A), S98.2
unnamed: D99.2 (A), S99.2
unnamed: D100.2 (A), S100.2
unnamed: D101.2 (A), S101.2
unnamed: D102.2 (A), S102.2
unnamed: D103.2 (A), S103.2
unnamed: D104.2 (DOUT), D105.4 (DIN)
unnamed: D105.2 (DOUT), D106.4 (DIN)
unnamed: D106.2 (DOUT), D107.4 (DIN)
unnamed: D107.2 (DOUT), D108.4 (DIN)
unnamed: D108.2 (DOUT), D109.4 (DIN)
unnamed: D109.2 (DOUT), D110.4 (DIN)
unnamed: D110.2 (DOUT), D111.4 (DIN)
unnamed: D111.2 (DOUT), D112.4 (DIN)
unnamed: D112.2 (DOUT), D113.4 (DIN)
unnamed: D113.2 (DOUT), D114.4 (DIN)
unnamed: D114.2 (DOUT), D115.4 (DIN)
unnamed: D115.2 (DOUT), D116.4 (DIN)
unnamed: D116.2 (DOUT), D117.4 (DIN)
unnamed: D117.2 (DOUT), D118.4 (DIN)
unnamed: D118.2 (DOUT), D119.4 (DIN)
unnamed: D119.2 (DOUT), D120.4 (DIN)
unnamed: D120.2 (DOUT), D121.4 (DIN)
unnamed: D121.2 (DOUT), D122.4 (DIN)
unnamed: D122.2 (DOUT), D123.4 (DIN)
unnamed: D123.2 (DOUT), D124.4 (DIN)
unnamed: D124.2 (DOUT), D125.4 (DIN)
unnamed: D125.2 (DOUT), D126.4 (DIN)
unnamed: D126.2 (DOUT), D127.4 (DIN)
unnamed: D127.2 (DOUT), D128.4 (DIN)
unnamed: D128.2 (DOUT), D129.4 (DIN)
unnamed: D129.2 (DOUT), D130.4 (DIN)
unnamed: D130.2 (DOUT), D131.4 (DIN)
unnamed: D131.2 (DOUT), D132.4 (DIN)
unnamed: D132.2 (DOUT), D133.4 (DIN)
unnamed: D133.2 (DOUT), D134.4 (DIN)
unnamed: D134.2 (DOUT), D135.4 (DIN)
unnamed: D135.2 (DOUT), D136.4 (DIN)
unnamed: D136.2 (DOUT), D137.4 (DIN)
unnamed: D137.2 (DOUT), D138.4 (DIN)
unnamed: D138.2 (DOUT), D139.4 (DIN)
unnamed: D139.2 (DOUT), D140.4 (DIN)
unnamed: D140.2 (DOUT), D141.4 (DIN)
unnamed: D141.2 (DOUT), D142.4 (DIN)
unnamed: D142.2 (DOUT), D143.4 (DIN)
unnamed: D143.2 (DOUT), D144.4 (DIN)
unnamed: D144.2 (DOUT), D145.4 (DIN)
unnamed: D145.2 (DOUT), D146.4 (DIN)
unnamed: D146.2 (DOUT), D147.4 (DIN)
unnamed: D147.2 (DOUT), D148.4 (DIN)
unnamed: D148.2 (DOUT), D149.4 (DIN)
unnamed: D149.2 (DOUT), D150.4 (DIN)
unnamed: D150.2 (DOUT), D151.4 (DIN)
unnamed: D151.2 (DOUT), D152.4 (DIN)
unnamed: D152.2 (DOUT), D153.4 (DIN)
unnamed: D153.2 (DOUT), D154.4 (DIN)
unnamed: D154.2 (DOUT), D155.4 (DIN)
unnamed: D155.2 (DOUT), D156.4 (DIN)
unnamed: D156.2 (DOUT), D157.4 (DIN)
unnamed: D157.2 (DOUT), D158.4 (DIN)
unnamed: D158.2 (DOUT), D159.4 (DIN)
unnamed: D159.2 (DOUT), D160.4 (DIN)
unnamed: D160.2 (DOUT), D161.4 (DIN)
unnamed: D161.2 (DOUT), D162.4 (DIN)
unnamed: D162.2 (DOUT), D163.4 (DIN)
unnamed: D163.2 (DOUT), D164.4 (DIN)
unnamed: D164.2 (DOUT), D165.4 (DIN)
unnamed: D165.2 (DOUT), D166.4 (DIN)
unnamed: D166.2 (DOUT), D167.4 (DIN)
unnamed: D167.2 (DOUT), D168.4 (DIN)
unnamed: D168.2 (DOUT), D169.4 (DIN)
unnamed: D169.2 (DOUT), D170.4 (DIN)
unnamed: D170.2 (DOUT), D171.4 (DIN)
unnamed: D171.2 (DOUT), D172.4 (DIN)
unnamed: D172.2 (DOUT), D173.4 (DIN)
unnamed: D173.2 (DOUT), D174.4 (DIN)
unnamed: D174.2 (DOUT), D175.4 (DIN)
unnamed: D175.2 (DOUT), D176.4 (DIN)
unnamed: D176.2 (DOUT), D177.4 (DIN)
unnamed: D177.2 (DOUT), D178.4 (DIN)
unnamed: D178.2 (DOUT), D179.4 (DIN)
unnamed: D179.2 (DOUT), D180.4 (DIN)
unnamed: D180.2 (DOUT), D181.4 (DIN)
unnamed: D181.2 (DOUT), D182.4 (DIN)
unnamed: D182.2 (DOUT), D183.4 (DIN)
unnamed: D183.2 (DOUT), D184.4 (DIN)
unnamed: D184.2 (DOUT), D185.4 (DIN)
unnamed: D185.2 (DOUT), D186.4 (DIN)
unnamed: D186.2 (DOUT), D187.4 (DIN)
unnamed: D187.2 (DOUT), D188.4 (DIN)
unnamed: D188.2 (DOUT), D189.4 (DIN)
unnamed: D189.2 (DOUT), D190.4 (DIN)
unnamed: D190.2 (DOUT), D191.4 (DIN)
unnamed: D191.2 (DOUT), D192.4 (DIN)
unnamed: D192.2 (DOUT), D193.4 (DIN)
unnamed: D193.2 (DOUT), D194.4 (DIN)
unnamed: D194.2 (DOUT), D195.4 (DIN)
unnamed: D195.2 (DOUT), D196.4 (DIN)
unnamed: D196.2 (DOUT), D197.4 (DIN)
unnamed: D197.2 (DOUT), D198.4 (DIN)
unnamed: D198.2 (DOUT), D199.4 (DIN)
unnamed: D199.2 (DOUT), D200.4 (DIN)
unnamed: D200.2 (DOUT), D201.4 (DIN)
unnamed: D201.2 (DOUT), D202.4 (DIN)
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

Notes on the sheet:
LED backlights
Keyboard matrix
OLED Display
YD RP2040
LED level shifter

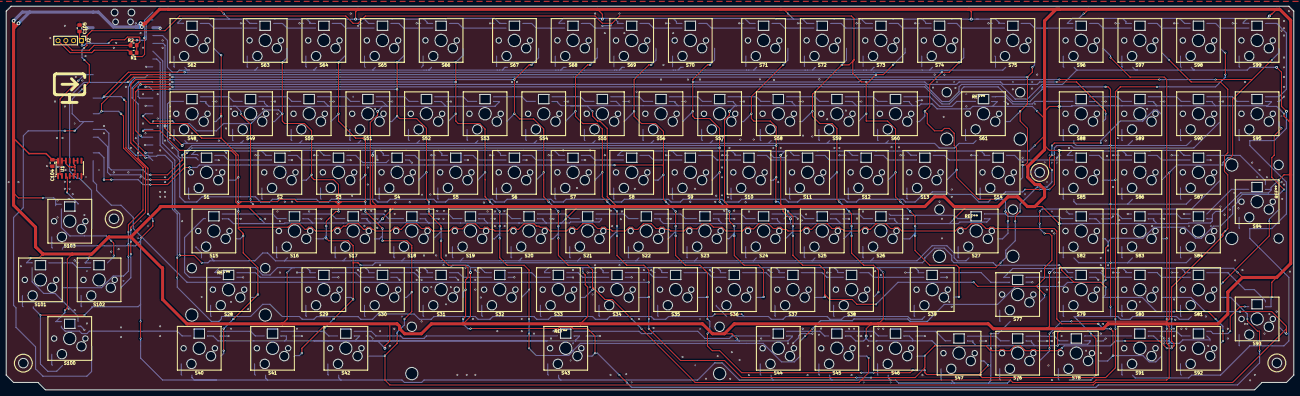
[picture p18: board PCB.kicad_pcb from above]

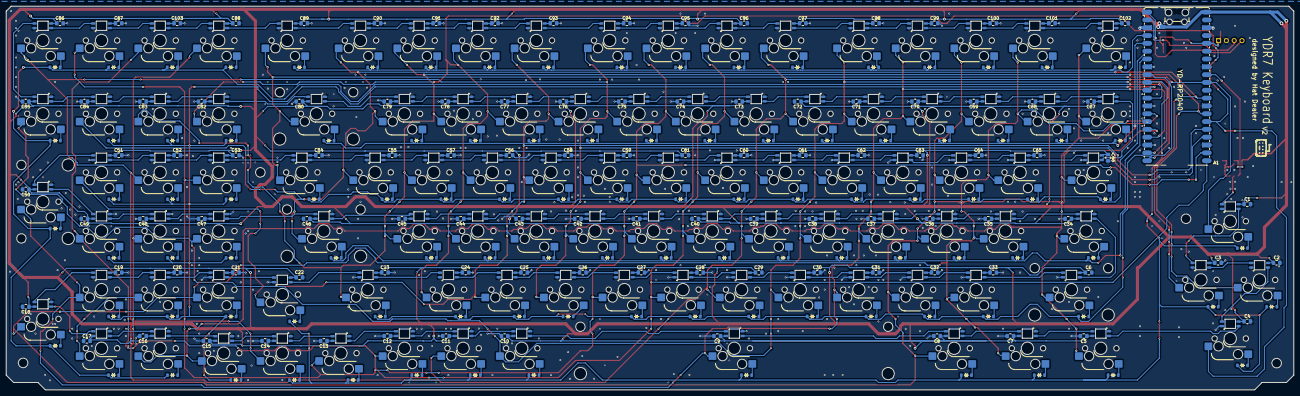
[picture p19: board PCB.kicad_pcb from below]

Board: 2 copper layers, 418.3 x 124.6 mm, 419 parts (310 on the bottom side), 234 nets.

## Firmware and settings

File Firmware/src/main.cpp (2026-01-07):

#include <pico/stdlib.h>
#include <pico/multicore.h>
#include <pico/mutex.h>

#include <atomic>

#include "config/themes.h"
#include "config/user_config.h"

#include "setup/HID_setup.h"
#include "setup/TUD_setup.h"
#include "setup/pin_setup.h"

#include "components/Keyboard.h"
#include "components/LED.h"

mutex_t LEDMutex;
mutex_t DisplayMutex;

std::atomic<bool> updateLEDRequest{false};
std::atomic<bool> updateDisplayRequest{false};

void MULTICORE_DataPushHandler(){
    while(true){
        if(updateLEDRequest.load(std::memory_order_acquire)){
            mutex_enter_blocking(&LEDMutex);
            LED::Show();
            mutex_exit(&LEDMutex);

            updateLEDRequest.store(false,  std::memory_order_release);
        }
        if(updateDisplayRequest.load(std::memory_order_acquire)){
            mutex_enter_blocking(&DisplayMutex);
            Display::Show();
            mutex_exit(&DisplayMutex);
            
            updateDisplayRequest.store(false,  std::memory_order_release);
        }
        sleep_ms(1);
    }
}

int main(){
    PinSetup_ALL();
    Display::InitialScreenWTest();

    tusb_init();

    do{
        tud_task();
        sleep_ms(1);
    }while(!tud_hid_ready());
    
    Display::ClearInitialScreen();

    static float LEDTickTimer = 0;
    constexpr float LEDTickTimerInterval = KEYBOARD_UPDATE_FREQUENCY / static_cast<float>(LED_UPDATE_FREQUENCY);
    static float DisplayTickTimer = 0;
    constexpr float DisplayTickTimerInterval = KEYBOARD_UPDATE_FREQUENCY / static_cast<float>(DISPLAY_UPDATE_FREQUENCY);

    mutex_init(&LEDMutex);
    mutex_init(&DisplayMutex);

    multicore_launch_core1(MULTICORE_DataPushHandler);

    Theme::ApplyTheme(1);

    while (true) {
        tud_task();

        uint8_t* pressedKeys = Keyboard::GetKeyPressIndexes();
        if (pressedKeys) {
            uint8_t report[6] = { 0 };

            for(uint8_t i = 0; i < 6; i++){
                if(pressedKeys[i] != 255){
                    report[i] = Keyboard::KeyMap[pressedKeys[i]];
                    
                    LED::ChangeColor(
                        KEYBOARD_KEY_TO_LED_INDEX[pressedKeys[i]], 
                        Theme::GetActiveColor(), 
                        15
                    );
                } else break;
            }
            tud_hid_keyboard_report(0, 0, report);
        } else {
            tud_hid_keyboard_report(0, 0, nullptr);
            
        }

        if(LEDTickTimer >= LEDTickTimerInterval){
            LEDTickTimer -= LEDTickTimerInterval;

            mutex_enter_blocking(&LEDMutex);
            LED::Tick();
            mutex_exit(&LEDMutex);
            
            updateLEDRequest.store(true, std::memory_order_release);
        }

        if(DisplayTickTimer >= DisplayTickTimerInterval){
            DisplayTickTimer -= DisplayTickTimerInterval;

            mutex_enter_blocking(&DisplayMutex);
            Display::UpdateMenu();
            mutex_exit(&DisplayMutex);

            updateDisplayRequest.store(true, std::memory_order_release);
        }

        static constexpr float KEYBOARD_SLEEP_TIME_MS = 1.0f / KEYBOARD_UPDATE_FREQUENCY * 1000.0f;
        LEDTickTimer += KEYBOARD_SLEEP_TIME_MS;
        DisplayTickTimer += KEYBOARD_SLEEP_TIME_MS;
        sleep_ms(KEYBOARD_SLEEP_TIME_MS);
    }

    return 0;
}

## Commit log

2025-10-29 Schematic with uncomplete PCB
    [PCB.kicad_pcb, PCB.kicad_sch]
2025-10-29 minor schematic change
    [PCB.kicad_sch]
2025-10-30 flipped condensators
    [PCB.kicad_pcb]
2025-10-31 did most of the wiring
    [PCB.kicad_sch]
2025-11-01 wiring is now without errors
2025-11-01 small changes to the PCB
2025-11-01 added BOM
    [BOM.csv]
2025-11-01 cosmetic changes to the PCB
2025-11-01 fixed firmware and changet the PCB a little
    [PCB.kicad_pcb]
2025-11-02 added decoupling capacitor near level shifter
    [BOM.csv, PCB.kicad_pcb, PCB.kicad_sch]
2025-11-02 added some vias to lower LEDs signal impedance
    [PCB.kicad_pcb]
2025-11-02 made the PCB not rectangle and updated BOM
    [BOM.csv, PCB.kicad_pcb]
2025-11-02 moved some vias around
    [PCB.kicad_pcb]
2025-11-04 wip CAD files
    [BOM.csv, Back.SLDPRT, PCB.kicad_pcb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]
2025-11-05 CAD models for keyboard casing
    [Assembly.SLDASM, Back.SLDPRT, back.STEP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]
2025-11-05 stl, readme and bom updates
    [BOM.csv, Back.SLDPRT, PCB.kicad_pcb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]
2025-11-05 addes sliced CAD files
    [1-back-1.STL, 1-back.SLDPRT, 1-back.STEP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]
2025-11-05 Added filament to the BOM
    [BOM.csv]
2025-11-05 updated the PCB a little bit
    [BOM.csv, PCB.kicad_pcb, PCB.kicad_sch]
2025-11-06 updated BOM
    [Assembly.SLDASM, BOM.csv]
2025-11-06 mini BOM update
    [BOM.csv]
2025-11-06 Updated BOM to add shiping costs
    [BOM.csv]
2025-11-07 Updated BOM, Assembly etc
    [Assembly.SLDASM, Assembly.STEP, BOM.csv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]
2025-11-07 updated gerber files
2025-11-08 fixed a layout error and updated the assembly with switches
    [Assembly.SLDASM, Kailh Polia.step, PCB.kicad_pcb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]
2025-11-19 updated CAD files & PCB
    [Assembly.SLDASM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]
2025-12-02 updated the case
    [1-back-1.STL, 1-back.SLDPRT, 1-back.STEP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]
2025-12-08 remade the NeoPixels on the PCB
    [PCB.kicad_pcb, PCB.kicad_sch]
2025-12-08 Added extra routes for the NeoPixels to even out power distribution
    [PCB.kicad_pcb, PCB.kicad_sch]
2025-12-10 Updated the PCB a bit
    [PCB-B_Cu.gbr, PCB-B_Mask.gbr, PCB-B_Paste.gbr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]
2025-12-10 mini update to YD-RP2040 footprint
    [PCB.kicad_pcb]
2025-12-10 updated screw holes on the PCB
    [PCB.kicad_pcb]
2025-12-23 Added basic keyboard functionality + minor CAD change
    [1-back.SLDPRT, 2-back.SLDPRT]
2025-12-23 changed up the LED colors
2025-12-23 file update + firmware LED control
    [1-back.SLDPRT, 1-back.STEP, 1-back.STL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]
